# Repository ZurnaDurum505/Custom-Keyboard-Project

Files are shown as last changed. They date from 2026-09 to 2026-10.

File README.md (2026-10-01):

# Custom-Keyboard-Project 
I started my keyboard by starting to make the PCB using Kicad. To do the PCB I had to do the schematics first by placing switches for the keys and adding diodes on every switch so the keyboard wont start "ghosting" when multiple keys are pressed. Then i added stabilizers for each key that was going to be larger than 2U. After placing everything I started wiring the keyboard making rows and columns so i can wire them to the Pico micro controller faster, and to finish it off i added my mounting holes at the corners of my design. After that I just assigned footprints and annotated my schematics. Also if you struggle with planning out your keyboard i recommend using this website https://www.keyboard-layout-editor.com/#/ It lets you design your own keyboard by placing keys and adjusting the how many U's you want your keys to be.
Keeb schematics pic
After the schematics I moved to the pcb editor where draw the outline of my pcb and  reorganized my keys, diode, and stabs inside the bcb outline(because it doesn’t come to you organized in the pcb editor). After everything looked how i wanted to order to be, i placed the pico inside the b b outline with its USB port facing outside and slightly outside of my pcb outline before I started firing the pcb. I wired my keys as columns on the front board and my diode as rows on the back board, making sure to not make any of the wires in the same board side touch eachother. After the wiring was done I started making a case for it on in shape CAD. I started by making a bottom plate slightly bigger than the pcb, them making walls that are around 10-15 mm tall. Before I did the top plate, I scratched 14mm to 14mm squares on every spot a key needed to go (and also sketch holes for your stabs I eyeballed the size for mine). After that was done I made the top plate around 3mm thick closing on the pcb and extrude removed the spaces the keyholes would be from my scetch, creating holes for my keys. Before you move onto customizing yourdesign make a 5 to 10mm hole on where your pico’s port would be. After that is up to you to make it look how you want, I added another layer not covering a rectangle area where keys would be and extrude removed to carve my logo. I did this project to learn new things but also to feel the joy of creating something, I am making this keyboard to my sister who was the person who motivated me to do it and i hope anyone doing this project learns something, feels the joy of creating something, and gets motivated by it.

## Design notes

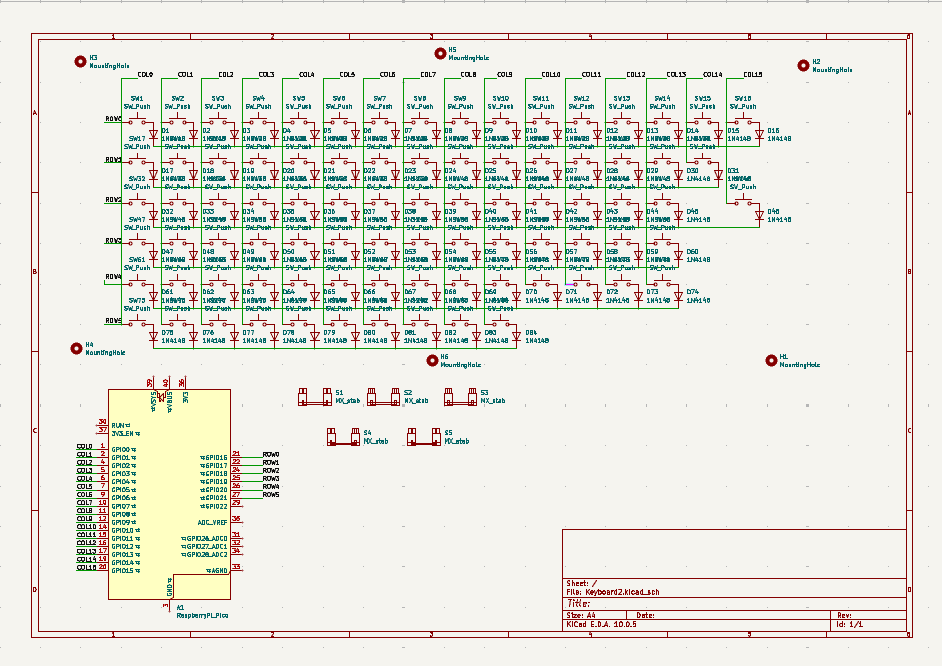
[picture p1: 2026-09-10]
media/schematic.png

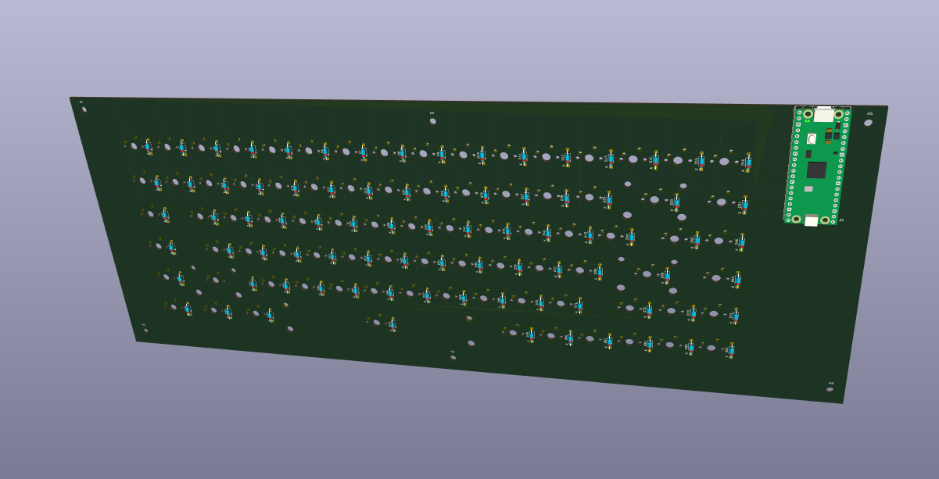
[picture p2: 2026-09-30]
media/pcb_final.png

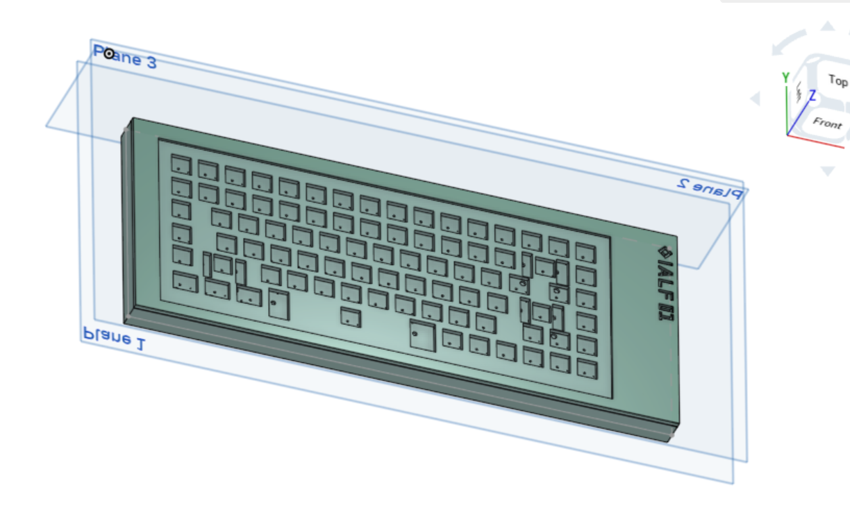
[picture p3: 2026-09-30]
media/case.png

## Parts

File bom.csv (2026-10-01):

Item Name | Qty | Price (total) (USD) | Item link | Notes
Orpheus Pico 3pcs | 1 | $13.99 | https://www.amazon.com/gp/product/B0CG9FWDDC/ref=ox_sc_act_title_9?smid=A2OEGRG2ZM4R5C&psc=1 | Could not find the Orpheus Pico, so getting a Raspberry Pi Pico with Type C port to replace it.
90 Pice Switches | 1 | $16.90 | https://www.amazon.com/Switches-Mechanical-Keyboard-Replaceable-Dustproof/dp/B0G1FX6C5B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
Diodes | 1 | $5.99 | https://www.amazon.com/EEEEE-Switching-MILLIAMP-Electronic-Silicon/dp/B0FC289DVH?s=industrial
139pcs Keycaps | 1 | $29.99 | https://www.amazon.com/gp/product/B09X1SYNQL/ref=ewc_pr_img_2?smid=AH4D7YJ4IREB6&th=1
Type-C Cable | 1 | $3.99 | https://www.amazon.com/gp/product/B0HFJKH6NQ/ref=ewc_pr_img_1?smid=ABVGHSPVH233I&psc=1
Soildering Iron | 1 | $11.99 | https://www.amazon.com/gp/product/B08R3515SF/ref=ox_sc_saved_title_3?smid=A19YGYI63H9AEE&th=1
Case Print | 1 | $99.12 | https://drive.google.com/file/d/1k3ZTB6_7JNoh-9K0Tnb4_iZtpu-KJ-al/view?usp=sharing
PCB | 5 | $57.23 | https://drive.google.com/file/d/1eYPGGNdbHDK-cmHtU9A1p2rJspJMZXRg/view?usp=sharing
Total Price (USD): | $239.20

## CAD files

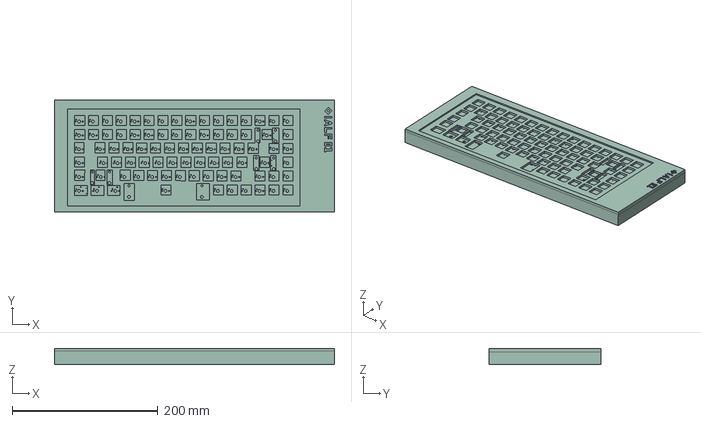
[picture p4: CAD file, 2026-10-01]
3D/model.step
384.3 x 154.1 x 22.0 mm

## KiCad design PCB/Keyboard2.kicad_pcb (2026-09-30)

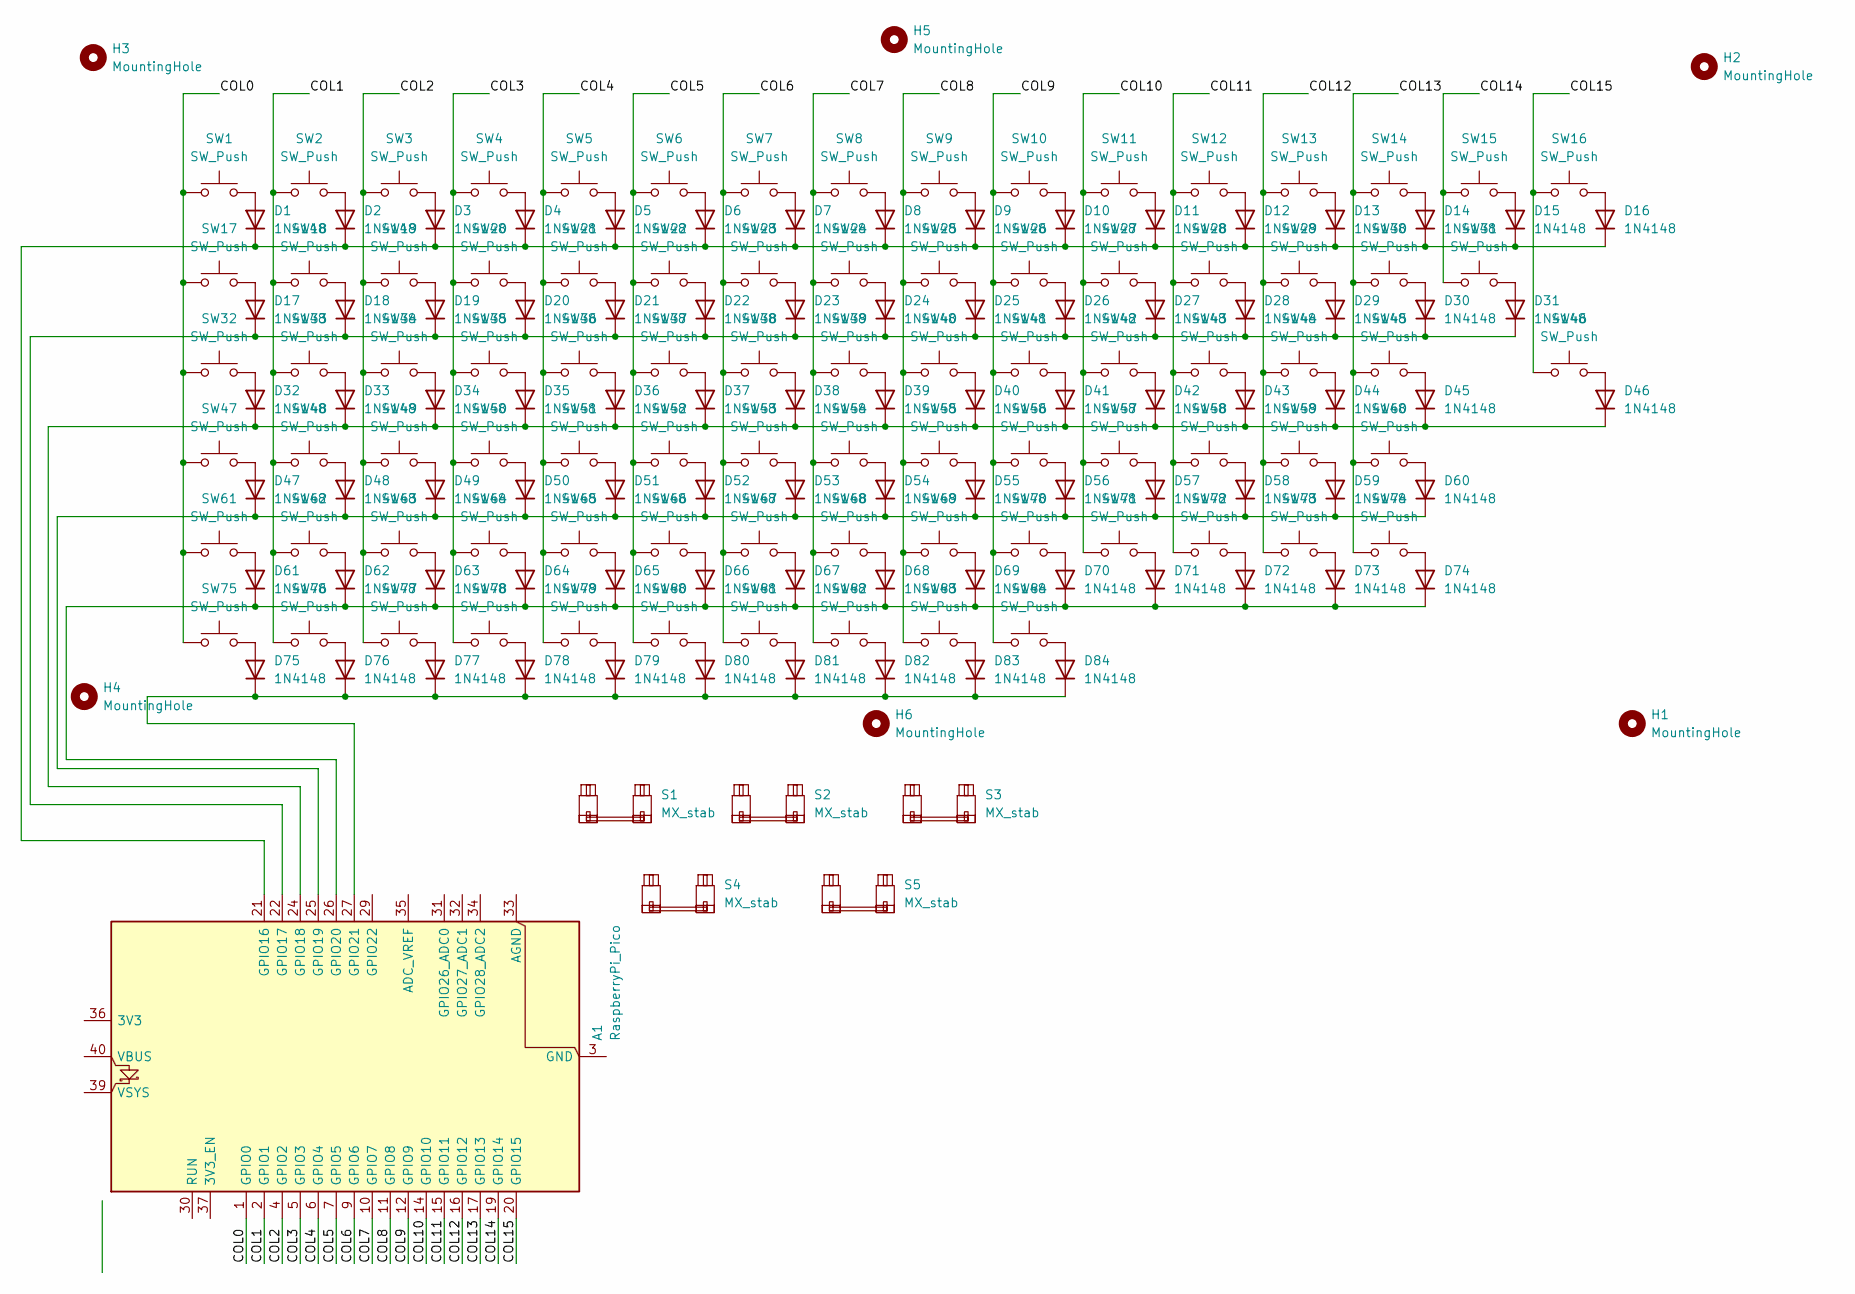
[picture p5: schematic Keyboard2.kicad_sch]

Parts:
A1: RaspberryPi_Pico; RaspberryPi_Pico_Common_THT
D1, D2, D3, D4, D5, D6, D7, D8, D9, D10, D11, D12, D13, D14, D15, D16, D17, D18, D19, D20, D21, D22, D23, D24, D25, D26, D27, D28, D29, D30, D31, D32, D33, D34, D35, D36, D37, D38, D39, D40, D41, D42, D43, D44, D45, D46, D47, D48, D49, D50, D51, D52, D53, D54, D55, D56, D57, D58, D59, D60, D61, D62, D63, D64, D65, D66, D67, D68, D69, D70, D71, D72, D73, D74, D75, D76, D77, D78, D79, D80, D81, D82, D83, D84: 1N4148; D_DO-35_SOD27_P7.62mm_Horizontal
H1, H2, H3, H4, H5, H6: MountingHole; MountingHole_3.2mm_M3
S1, S2, S3, S4, S5: MX_stab; STAB_MX_P_6.25u
SW1, SW2, SW3, SW4, SW5, SW6, SW7, SW8, SW9, SW10, SW11, SW12, SW13, SW14, SW15, SW16, SW17, SW18, SW19, SW20, SW21, SW22, SW23, SW24, SW25, SW26, SW27, SW28, SW29, SW30, SW31, SW32, SW33, SW34, SW35, SW36, SW37, SW38, SW39, SW40, SW41, SW42, SW43, SW44, SW45, SW46, SW47, SW48, SW49, SW50, SW51, SW52, SW53, SW54, SW55, SW56, SW57, SW58, SW59, SW60, SW61, SW62, SW63, SW64, SW65, SW66, SW67, SW68, SW69, SW70, SW71, SW72, SW73, SW74, SW75, SW76, SW77, SW78, SW79, SW80, SW81, SW82, SW83, SW84: SW_Push; SW_MX_1u

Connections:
/COL0: A1.1 (GPIO0), SW1.1, SW17.1, SW32.1, SW47.1, SW61.1, SW75.1
/COL1: A1.2 (GPIO1), SW2.1, SW18.1, SW33.1, SW48.1, SW62.1, SW76.1
/COL2: A1.4 (GPIO2), SW3.1, SW19.1, SW34.1, SW49.1, SW63.1, SW77.1
/COL3: A1.5 (GPIO3), SW4.1, SW20.1, SW35.1, SW50.1, SW64.1, SW78.1
/COL4: A1.6 (GPIO4), SW5.1, SW21.1, SW36.1, SW51.1, SW65.1, SW79.1
/COL5: A1.7 (GPIO5), SW6.1, SW22.1, SW37.1, SW52.1, SW66.1, SW80.1
/COL6: A1.9 (GPIO6), SW7.1, SW23.1, SW38.1, SW53.1, SW67.1, SW81.1
/COL7: A1.10 (GPIO7), SW8.1, SW24.1, SW39.1, SW54.1, SW68.1, SW82.1
/COL8: A1.11 (GPIO8), SW9.1, SW25.1, SW40.1, SW55.1, SW69.1, SW83.1
/COL9: A1.12 (GPIO9), SW10.1, SW26.1, SW41.1, SW56.1, SW70.1, SW84.1
/COL10: A1.14 (GPIO10), SW11.1, SW27.1, SW42.1, SW57.1, SW71.1
/COL11: A1.15 (GPIO11), SW12.1, SW28.1, SW43.1, SW58.1, SW72.1
/COL12: A1.16 (GPIO12), SW13.1, SW29.1, SW44.1, SW59.1, SW73.1
/COL13: A1.17 (GPIO13), SW14.1, SW30.1, SW45.1, SW60.1, SW74.1
/COL14: A1.19 (GPIO14), SW15.1, SW31.1
/COL15: A1.20 (GPIO15), SW16.1, SW46.1
unnamed: A1.3 (GND), A1.8 (GND), A1.13 (GND), A1.18 (GND), A1.23 (GND), A1.28 (GND), A1.38 (GND)
unnamed: A1.21 (GPIO16), D1.1 (K), D2.1 (K), D3.1 (K), D4.1 (K), D5.1 (K), D6.1 (K), D7.1 (K), D8.1 (K), D9.1 (K), D10.1 (K), D11.1 (K), D12.1 (K), D13.1 (K), D14.1 (K), D15.1 (K), D16.1 (K)
unnamed: A1.22 (GPIO17), D17.1 (K), D18.1 (K), D19.1 (K), D20.1 (K), D21.1 (K), D22.1 (K), D23.1 (K), D24.1 (K), D25.1 (K), D26.1 (K), D27.1 (K), D28.1 (K), D29.1 (K), D30.1 (K), D31.1 (K)
unnamed: A1.24 (GPIO18), D32.1 (K), D33.1 (K), D34.1 (K), D35.1 (K), D36.1 (K), D37.1 (K), D38.1 (K), D39.1 (K), D40.1 (K), D41.1 (K), D42.1 (K), D43.1 (K), D44.1 (K), D45.1 (K), D46.1 (K)
unnamed: A1.25 (GPIO19), D47.1 (K), D48.1 (K), D49.1 (K), D50.1 (K), D51.1 (K), D52.1 (K), D53.1 (K), D54.1 (K), D55.1 (K), D56.1 (K), D57.1 (K), D58.1 (K), D59.1 (K), D60.1 (K)
unnamed: A1.26 (GPIO20), D61.1 (K), D62.1 (K), D63.1 (K), D64.1 (K), D65.1 (K), D66.1 (K), D67.1 (K), D68.1 (K), D69.1 (K), D70.1 (K), D71.1 (K), D72.1 (K), D73.1 (K), D74.1 (K)
unnamed: A1.27 (GPIO21), D75.1 (K), D76.1 (K), D77.1 (K), D78.1 (K), D79.1 (K), D80.1 (K), D81.1 (K), D82.1 (K), D83.1 (K), D84.1 (K)
unnamed: D1.2 (A), SW1.2
unnamed: D2.2 (A), SW2.2
unnamed: D3.2 (A), SW3.2
unnamed: D4.2 (A), SW4.2
unnamed: D5.2 (A), SW5.2
unnamed: D6.2 (A), SW6.2
unnamed: D7.2 (A), SW7.2
unnamed: D8.2 (A), SW8.2
unnamed: D9.2 (A), SW9.2
unnamed: D10.2 (A), SW10.2
unnamed: D11.2 (A), SW11.2
unnamed: D12.2 (A), SW12.2
unnamed: D13.2 (A), SW13.2
unnamed: D14.2 (A), SW14.2
unnamed: D15.2 (A), SW15.2
unnamed: D16.2 (A), SW16.2
unnamed: D17.2 (A), SW17.2
unnamed: D18.2 (A), SW18.2
unnamed: D19.2 (A), SW19.2
unnamed: D20.2 (A), SW20.2
unnamed: D21.2 (A), SW21.2
unnamed: D22.2 (A), SW22.2
unnamed: D23.2 (A), SW23.2
unnamed: D24.2 (A), SW24.2
unnamed: D25.2 (A), SW25.2
unnamed: D26.2 (A), SW26.2
unnamed: D27.2 (A), SW27.2
unnamed: D28.2 (A), SW28.2
unnamed: D29.2 (A), SW29.2
unnamed: D30.2 (A), SW30.2
unnamed: D31.2 (A), SW31.2
unnamed: D32.2 (A), SW32.2
unnamed: D33.2 (A), SW33.2
unnamed: D34.2 (A), SW34.2
unnamed: D35.2 (A), SW35.2
unnamed: D36.2 (A), SW36.2
unnamed: D37.2 (A), SW37.2
unnamed: D38.2 (A), SW38.2
unnamed: D39.2 (A), SW39.2
unnamed: D40.2 (A), SW40.2
unnamed: D41.2 (A), SW41.2
unnamed: D42.2 (A), SW42.2
unnamed: D43.2 (A), SW43.2
unnamed: D44.2 (A), SW44.2
unnamed: D45.2 (A), SW45.2
unnamed: D46.2 (A), SW46.2
unnamed: D47.2 (A), SW47.2
unnamed: D48.2 (A), SW48.2
unnamed: D49.2 (A), SW49.2
unnamed: D50.2 (A), SW50.2
unnamed: D51.2 (A), SW51.2
unnamed: D52.2 (A), SW52.2
unnamed: D53.2 (A), SW53.2
unnamed: D54.2 (A), SW54.2
unnamed: D55.2 (A), SW55.2
unnamed: D56.2 (A), SW56.2
unnamed: D57.2 (A), SW57.2
unnamed: D58.2 (A), SW58.2
unnamed: D59.2 (A), SW59.2
unnamed: D60.2 (A), SW60.2
unnamed: D61.2 (A), SW61.2
unnamed: D62.2 (A), SW62.2
unnamed: D63.2 (A), SW63.2
unnamed: D64.2 (A), SW64.2
unnamed: D65.2 (A), SW65.2
unnamed: D66.2 (A), SW66.2
unnamed: D67.2 (A), SW67.2
unnamed: D68.2 (A), SW68.2
unnamed: D69.2 (A), SW69.2
unnamed: D70.2 (A), SW70.2
unnamed: D71.2 (A), SW71.2
unnamed: D72.2 (A), SW72.2
unnamed: D73.2 (A), SW73.2
unnamed: D74.2 (A), SW74.2
unnamed: D75.2 (A), SW75.2
unnamed: D76.2 (A), SW76.2
unnamed: D77.2 (A), SW77.2
unnamed: D78.2 (A), SW78.2
unnamed: D79.2 (A), SW79.2
unnamed: D80.2 (A), SW80.2
unnamed: D81.2 (A), SW81.2
unnamed: D82.2 (A), SW82.2
unnamed: D83.2 (A), SW83.2
unnamed: D84.2 (A), SW84.2

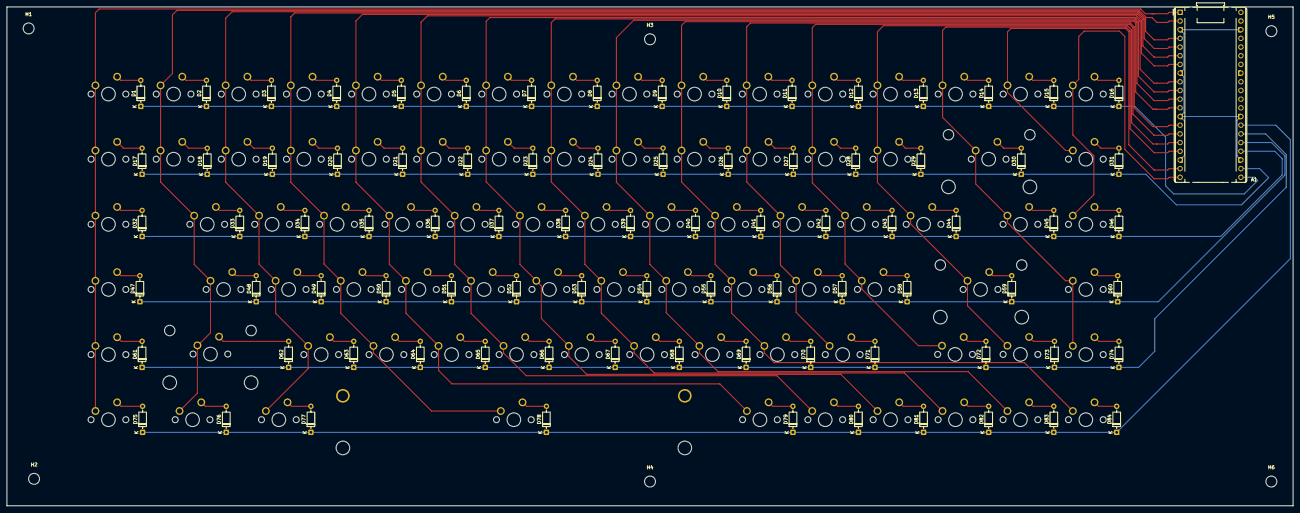
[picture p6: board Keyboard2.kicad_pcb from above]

Board: 2 copper layers, 376.2 x 145.9 mm, 179 parts (0 on the bottom side), 107 nets.

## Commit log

2026-09-30 Rename BOM - Sheet1.csv to BOM.csv
    [BOM.csv]
2026-10-01 Rename BOM - Sheet1 (1).csv to bom.csv
    [bom.csv]
2026-10-01 Add new 3D model file
    [model.step]
2026-10-01 Enhance README with PCB design and case details
    Added detailed description of PCB design and case creation process for the custom keyboard project.
2026-10-01 Enhance KEEB journal with detailed PCB and case design steps
    Expanded the journal entry with detailed steps on creating the PCB and case for the keyboard, including tips and recommendations for planning.
